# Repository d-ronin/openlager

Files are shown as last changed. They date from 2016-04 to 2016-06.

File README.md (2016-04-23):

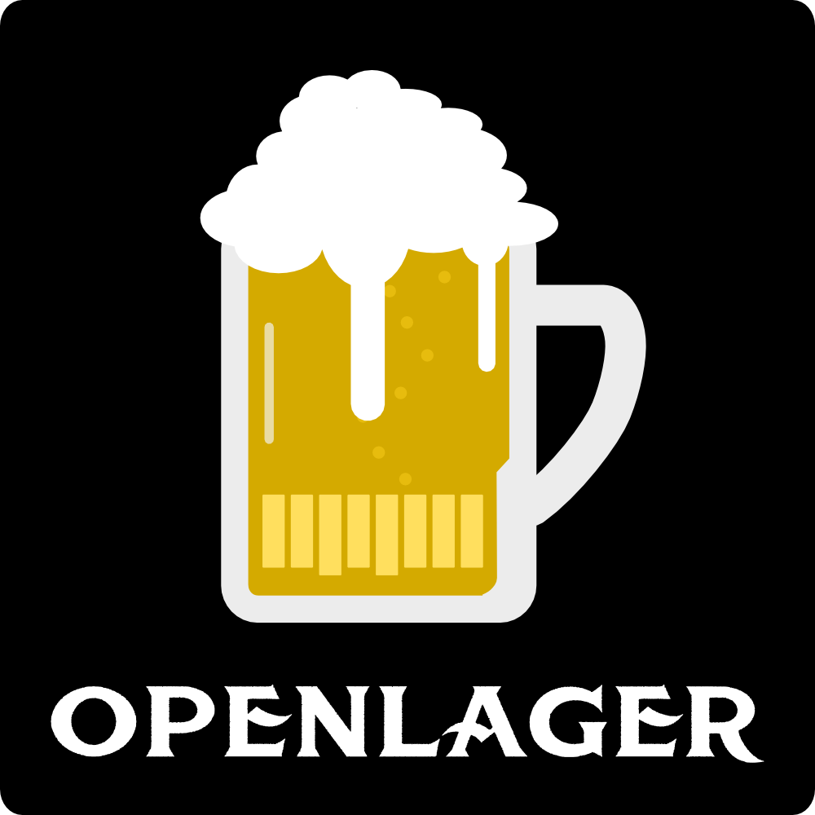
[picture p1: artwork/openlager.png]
openlager

STM32F4 based logging dongle for **HIGH RATE** logging

This project is inspired by [OpenLog](https://github.com/sparkfun/OpenLog).

*Why do something new?*  To attain higher rates!  The **openlager** hardware can accept data at high rates using slave SPI or fast async serial.  It uses a 4-wide SDIO interface to the card to support higher peak logging rates.  And the reasonable amount of memory buffer on the STM32F411 lets us ride out times when the SD card is busy erasing or doing other housekeeping without losing data.

The **openlager** hardware design and firmware are produced by the [dRonin](http://dronin.org) project, which produces high-quality flight controller software for drone racing and autonomous flight.  To log everything that's happening in a lossless fashion, high rate logs are required.  But we anticipate it being useful for a wide variety of applications.

# Licenses

The **openlager** hardware in `hardware/` is licensed under a Creative Commons Attribution 4.0 International License (CC BY 4.0), as contained in `hardware/LICENSE.txt`

The **openlager** firmware (and bootloader) in `src/`, `loader/`, and `shared/` is licensed under a simplified BSD license as found in `src/LICENSE.txt`

The openlager **logo** may only be used with permission from the dRonin project.

The **fatfs** library in `libs/fatfs` is licensed under the one-clause BSD license as found in the source files in that directory.

The **STM32F4xx_StdPeriph_Driver** library in `libs/STM32F4xx_StdPeriph_Driver` is largely licensed under a restrictive license that limits its usage to ST family processors.  To use this software on non-ST parts, the dependency on this library code must be removed.  Portions of this code (the `core_cm*` include headers) are licensed under a permissive 3 clause BSD license from ARM, as noted in the individual files.

The **mmcreg.h** file from FreeBSD in `libs/inc` is licensed under a simplified BSD license.

The **jsmn** library in `libs` is licensed under the MIT license.

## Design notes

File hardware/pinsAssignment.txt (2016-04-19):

Main interface:
	Pin 1 - SO
	Pin 2 - RX/CK
	Pin 3 - TX/CS
	Pin 4 - 5V
	Pin 5 - GND
	Pin 6 - SI
	Pin 7 - NRST

SD Card Interface:
	SDIO_CK  - PB15
	SDIO_CMD - PA6
	SDIO_D0  - PB7
	SDIO_D1  - PA8
	SDIO_D2  - PA9
	SDIO_D3  - PB5

FC Interface:
	UART1_TX/SPI1_NSS  - PA15
	UART1_RX/SPI1_SCK  - PA3
	SPI1_MISO          - PA4
	SPI1_MOSI          - PA7

Status LED:
	Active LOW - PB9

BOOT Interface:
	BOOT0 - 10k pull-down, pad for jumpering to +3V3
	BOOT1 - 10k pull-down

Bootloader Interface:
	RX_SCK - shared with SWDIO
	MOSI   - shared with SWCLK
	NRST

HW Rev ID:
	Rev A: PB12 PB13 PB14 - All LOW

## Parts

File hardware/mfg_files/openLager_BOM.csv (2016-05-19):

Reference | Quantity | Value | Footprint | Datasheet | Mfg Name | Mfg PN | Link
C1 C4 | 2 | 10uF | openLagerFootprints:C_0402 | http://datasheet.octopart.com/CL05A106MP5NUNC-Samsung-datasheet-34153002.pdf | Samsung | CL05A106MP5NUNC | https://octopart.com/cl05a106mp5nunc-samsung-22457395
C5 | 1 | 1uF | openLagerFootprints:C_0402 | http://datasheet.octopart.com/GRM-Series-Murata-datasheet-family-27.pdf | Murata | GRM155R70J105MA12D | https://octopart.com/grm155r70j105ma12d-murata-23261089
C6 | 1 | 4.7uF | openLagerFootprints:C_0402 | http://www.samsungsem.com/kr/support/product-search/mlcc/__icsFiles/afieldfile/2015/08/14/S_CL05A475MQ5NQNC.pdf | Samsung | CL05A475MQ5NQNC | https://octopart.com/cl05a475mq5nqnc-samsung-24957780
C3 C7 C8 | 3 | 0.1uF | openLagerFootprints:C_0402 | http://datasheet.octopart.com/GRM155R70J104KA01D-Murata-datasheet-14400549.pdf | Murata | GRM155R70J104KA01D | https://octopart.com/grm155r70j104ka01d-murata-17930200
D1 | 1 | LG L29K-F2J1-24 | openLagerFootprints:LED_0603 | http://datasheet.octopart.com/LG-L29K-F2J1-24-Osram-datasheet-41480516.pdf | Osram Opto | LG L29K-F2J1-24 | https://octopart.com/lg+l29k-f2j1-24-osram+opto-31119809
D2 | 1 | LS L29K-G1J2-1-Z | openLagerFootprints:LED_0603 | http://datasheet.octopart.com/Q65110A1757-Osram-Opto-datasheet-31819788.pdf | Osram Opto | LS L29K-G1J2-1-Z | https://octopart.com/ls+l29k-g1j2-1-z-osram+opto-31093939
J1 | 1 | CONN_01X06 | openLagerFootprints:Socket_Strip_Straight_1x06 | DNP | DNP | DNP | DNP
J2 | 1 | DM3CS-SF | openLagerFootprints:HRS_DM3CS-SF | http://datasheet.octopart.com/DM3CS-SF-Hirose-datasheet-62290579.pdf | Hirose | DM3CS-SF | https://octopart.com/dm3cs-sf-hirose-44525751
R1 R3 R4 | 3 | 10k | openLagerFootprints:R_0402 | http://datasheet.octopart.com/RC0402JR-0710KL-Yageo-datasheet-10408619.pdf | Yageo | RC0402JR-0710KL | https://octopart.com/rc0402jr-0710kl-yageo-55458470
R12 R13 | 2 | 330R | openLagerFootprints:R_0402 | http://datasheet.octopart.com/RC0402JR-07330RL-Yageo-datasheet-10408619.pdf | Yageo | RC0402JR-07330RL | https://octopart.com/rc0402jr-07330rl-yageo-40021082
R2 | 1 | DNP | openLagerFootprints:R_0402 | DNP | DNP | DNP | DNP
R5 R6 R7 R8 | 4 | 22R | openLagerFootprints:R_0402 | http://datasheet.octopart.com/RC0402JR-0722RL-Yageo-datasheet-10408619.pdf | Yageo | RC0402JR-0722RL | https://octopart.com/rc0402jr-0722rl-yageo-1173206
R10 R9 | 2 | 47k | openLagerFootprints:R_0402 | http://datasheet.octopart.com/RC0402JR-0747KL-Yageo-datasheet-10408619.pdf | Yageo | RC0402JR-0747KL | https://octopart.com/rc0402jr-0747kl-yageo-39834460
TP1 | 1 | TEST_1P | openLagerFootprints:Socket_Strip_Straight_1x01 | DNP | DNP | DNP | DNP
TP2 TP3 | 2 | TEST_1P | openLagerFootprints:TP | DNP | DNP | DNP | DNP
U1 | 1 | STM32F411CEUx | openLagerFootprints:QFN-48-1EP_7x7mm_Pitch0.5mm | http://datasheet.octopart.com/STM32F411CEU6-STMicroelectronics-datasheet-27102711.pdf | ST Microelectronics | STM32F411CEU6 | https://octopart.com/stm32f411ceu6-stmicroelectronics-47202664
U2 | 1 | SPX3819M5-L-3-3 | openLagerFootprints:SOT95P280X145-5N | http://datasheet.octopart.com/SPX3819M5-L-3-3-TR-Exar-datasheet-13046336.pdf | Exar | SPX3819M5-L-3-3/TR | https://octopart.com/spx3819m5-l-3-3%2Ftr-exar-9290124
Y1 | 1 | CSTCE8M00G15L99 | openLagerFootprints:X3-SMD-3.6X1.3X0.8MM | http://datasheet.octopart.com/CSTCE8M00G15L99-R0-Murata-datasheet-13544362.pdf | Murata | CSTCE8M00G15L99-R0 | https://octopart.com/cstce8m00g15l99-r0-murata-17751576

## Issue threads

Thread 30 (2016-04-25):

SDIO receive / transmit should use DMA

mlyle, 2016-04-25:
Along with trying to be aligned / zerocopy in all cases...

mlyle, 2016-04-25:
This is probably the limiting factor preventing higher USART rates right now.  Very very easy to underrun the FIFO.  (get 'WFLAG' morse after a few seconds sustained at 576000 bps)

mlyle, 2016-04-26:
Adding retries (#31) gets around the 'WFLAG' for now, but that's hardly good for performance...

mlyle, 2016-05-02:
1.5megabaud pegged loses nothing currently.  2megabaud pegged loses occasional bits when fully pegged-- e.g. first loss is 200 bytes 1331000-ish bytes into a session.

Gyros+accels+attitude+stabilizationdesired+actuatordesired uavtalk:
```
12+16+28+24+17=97
97 + 11*5=152
```
results in 152000 characters per second at 1000Hz, or precisely 76% utilization on a 2mbaud channel.  This should be absolutely no problem for loss with the current scenario.  And there's still multiblock writes and a few K of buffering available to make this work better.

Closed 2016-05-02.

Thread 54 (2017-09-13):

improvement - flush & new file

LubinKerhuel, 2017-09-13:
First, let's say this logger is great and support much higher logging rate than its openlog counterpart. I've been looking for it for a very long time. Radio link to log were so-so, and openlog was too slow.

There are few pin which seems not used when using the UART connexion ; Is there any possibility to use one pin to force flush of current log and stop log when toggled to 0, and start a new file when toggled back to 1 ?
Currently, I added one wire which is doing it in a tiny hole nearby TP2 (might be a reset pin?). But that is certainly not the best way to do even if it works.

Another side remark: green led is too bright compared to red one. Red led is the one which provide useful information in the field, but I can hardly see it.

mlyle, 2017-09-13:
Thanks for the feedback.  --- can look into the possibility of doing this.

Where'd you get yours?  Note that I made a small batch myself, but all current production is just from Airbot who downloaded the design files and chose their own components/LEDs etc to put on.

LubinKerhuel, 2017-09-15:
I found only 2 place to buy it. I pick it at Airbot because of its slightly lower shipping rate for my place as I remember (France). I would pick the other one next time if it is the "original" one (yours?).

On performance feedback: setting the baudrate at 2 470 000, using 45% of the bandwidth (10.9 kbyte/s) for 15 minutes ~ half an hour. I get 0% error with old SD Cards formatted with either fat16 or fat32. That's all ok. (data recorded from a dsPIC)

kaspergrubbe, 2019-05-14:
@mlyle Is the one from RDQ from you or from Airbot https://www.readytoflyquads.com/high-rate-f4-data-logger-openlager ?

I would like to buy one, but would prefer to buy from dRonin.

tracernz, 2019-05-16:
@kaspergrubbe Buy it from wherever you can get it. The idea of making the design fully open from the start was that as many manufacturers as possible would pick it up and make the board easily available for everyone.

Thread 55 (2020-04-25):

Help diagnosing if working?

dan-van, 2020-04-25:
Hi I've been trying to connect an OpenLager (purchased through Amazon.com) to a MATEKF405 running Betaflight 4.1.1.
No joy. I'm beginning to suspect maybe a problem with Betaflight, or my FC, but it would be nice to know OpenLager is working.
I bought a DigitalLogic analyser, but my FC doesn't seem to be trying to pull voltage low on the TX UARTS when they are set to Blackbox (ok, there is actually a single pulse on board startup, but nothing after that).
If I get a USB -> UART bridge, is it somehow possible to write data to the openlager unit from my laptop?

--- more detail on my betaflight setup ---
I get a zero-byte LOG000.TXT file each time I power up the flight controller.
I have betaflight set up to activate BB logging when armed.
Arming / disarming does not create a new file. Only powering the board creates a new file.
I've tried numerous different baud rates and 2 different TX pads on my FC (obviously updating the LAGER.CFG file).
Changing preallocGrow=true causes a 105mb log file to be written (assuming related to the preallocBytes : 104857600 setting). Obviously I can't parse this file.

Many thanks!

dan-van, 2020-04-27:
An update to this.
I got an FT232 and can send asci to the OpenLager.
The unit logs different length LOG000.TXT files depending on how many chars I type (using `screen /dev/...usbserial... <baud>`). The strange thing is that the file is just full of 0x00 values, no asci chars (I was expecting it to just capture the data on the TX line).
Maybe I've got some other config problems or somehow mismatched baud rates, but should I expect to type asci in a terminal and capture the same bytestream on the openlager?

tracernz, 2020-04-27:
> should I expect to type asci in a terminal and capture the same bytestream on the openlager?

Yes, that should be what happens. The most likely scenario is one or more of the parameters is mismatched (baud rate, parity, stop bits), most likely baud rate. The openlager defaults to 115200 baud, but can be overridden with the config file (lager.cfg on the SD card, which will be created from defaults if it doesn't exist). The other parameters cannot be changed on the openlager.

dan-van, 2020-04-27:
Many thanks, I'll use something more controllable than 'screen' for partiy bits etc.
Closing the question: Having an FT232RL seems like the best way to verify operation (I guess technically there could be a self-test mode that relies on TX and RX being bridged on the OpenLager, but seems like poor effort / reward at this stage).

In case it helps anyone else (some other things that had me puzzled for a while):
Betaflight (4.1.1) with `blackbox_mode=NORMAL` doesn't start emitting data until the quad is fully armed. i.e. just configuring Blackbox to start in line with your 'arm' switch from your transmitter is not sufficient. The board needs to pass all pre-arm checks (i.e. go to full 'props spinning', and not have USB attached!).

Setting blackbox_mode=ALWAYS does emit UART data from power-on (seen on logic probe), but it's not really designed to work (e.g. missing headers are probably expected) and at time of writing the OpenLager didn't actually flush any data. I've probably messed up baud rates. Once I've verified capturing accurate ascii data from my laptop I'll go back to that.

Many thanks for the project!

Closed 2020-04-27.

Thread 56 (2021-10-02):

Does 4 bit mode really work ?  It is turned off in openlager.c's sd_init() call

mirov, 2021-10-02:
I found that my openlager running an image built from this Github source has a "false" parameter to the sd_init() call in openlager.c, and that means "don't use fourbit mode".  Is it turned off for a reason ?  I flipped it to true and can log for a while, but then it hangs.  Is that because the HW reference design only has a 47K pullup on SDIO_D0 ?  The other pins seem to have the pullups in the STM32 GPIOs turned on, but perhaps they are too weak for 19.2MHz.

mlyle, 2021-10-02:
It's turned off because SD bandwidth was not limiting performance on any of the cards we used.  The limiting factor wasn't the bus interface but the amount of time the card spent busy after I/O requests.  Bigger buffers / STM32F412, allowing bigger I/O operations per flush, would make a bigger difference than bus speed.

Of course, there's been a couple of years in progress in cards, so maybe there's some cards that would benefit from 4X now.  It was never really tested.

Pullup on SD bus lines are required during initialization but are not used during signalling-- the card enters a push-pull state.  A 47k pullup would not be fast enough for open collector at 1MHz, let alone 19.2MHz.  So that is not likely to be your issue.

mirov, 2021-10-02:
Hi Michael, I'll bet you were surprised to see activity on this after a few
years of quiet.  Hmmm, I wasn't sure if the 47K was simply there to hold
the high state.

I've got the Lager in a power sensitive design and am trying to find knobs
to drop consumption.  I'm sending data in bursts at 1Mbps, but at an
average of about 64KB/sec.  I found that things seem to be stable with the
core clock rate dropped down to 48MHz, and the SD clock down to 9.6 (that
saves around 10mA).  I'm looking at dropping my supply rail down to 2.7V,
which I believe will be OK with the newer 32GB cards I'm using - and that
will drop my upstream battery current by about 10% more.  I found that
preallocating a large enough block drops the power as well.

The once seemingly huge 128KB buffer of the 'F11 only gives me a few
seconds of buffer, but if it isn't keeping up my application runs so long
that a bigger buffer isn't going to help.

Oddly, every now and then I can get the device to log at a really low (like
half) power consumption.  Are there any magic block sizes/timing
preferences that I can exploit to keep it in a more efficient mode ?  I can
with some effort change the size of my serial data blocks, batch them up,
etc.  At the moment I'm logging in ASCII 'cause it is so easy to debug and
parse.  I can cut my byte count down by 2-3x if I switch to binary, but it
isn't clear if that will help the STM/uSD save power (busywaits instead of
sleeps for example).

-Russ

On Sat, Oct 2, 2021 at 3:09 PM Michael Lyle ***@***.***>
wrote:

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

mlyle, 2021-10-03:
Interesting.   Downclocking wouldn't be the first thing I'd do-- I'd try to race-to-sleep instead.

Looks like right now usart_receive_chunk busywaits, so getting a wait-for-interrupt in there would likely be helpful.

Currently a bunch of peripheral clocks are on that aren't needed.  But then a lot of them can be disabled-- e.g. when SD is not doing a transaction, the peripheral can be paused.  It would be better to keep the clock rate high and then disable the clock as quickly as possible after a transaction finishes.

mirov, 2021-10-03:
Oh, I'd also much prefer full speed clocks (at least those that I need) and
sleeping the CPU until something wakes it up.  Add in some DMA to keep it
sleeping until things are really done and the power should be pretty low.
Alas, I have never worked with the STM series (I'm mostly a nRF52 guy).

With the core clock slowed down I get lower power, but the tradeoff is that
I also get periodic hangs with the LED stuck on.

-Russ

On Sat, Oct 2, 2021 at 6:49 PM Michael Lyle ***@***.***>
wrote:

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

mlyle, 2021-10-03:
Try calling __WFI in the loop in usart_receive_chunk.

mlyle, 2021-10-03:
(note SD uses DMA; though we don't sleep during SD transactions either.  But making USART use DMA is much harder, because we're trying to adaptively adjust our flush behavior based on both what the card is doing and the arrival rate of information).

mirov, 2021-10-03:
That saved about 30% of what it was consuming, that was a nice suggestion
(and I would bet that it doesn't introduce any odd instabilities).   I
assume we're waking up for any INT.  Are there reliable sources always
running to be sure we don't snooze forever in that loop ?  I don't know if
for example there's a timer running that periodically pops and will always
nudge us to check the loop termination condition.  If so, then are there
other spots we're spinning for significant amounts of time that we could
play the same trick ?  For example in shared/sdio.c there's a loop waiting
for SDIO_STA_DATAEND that from your earlier comments sounds like we spend
some time in.  I dropped a WFI in there and it seems like it save perhaps
1/2 mA (which I'll take, thank you).   But again, I don't know if that
introduces a possible deadlock...

I really appreciate the help !

-Russ

On Sat, Oct 2, 2021 at 9:35 PM Michael Lyle ***@***.***>
wrote:

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

mlyle, 2021-10-03:
The two things that allow leaving the USART loop are either a UART interrupt or a timeout expiring (and the time is updated by the systick "interrupt").  So there's no cost to performance there.

The same isn't quite true of the SDIO stuff, which isn't interrupt driven presently.  Systick will still show up and knock you out of that eventually, but there may be times that the sd bus is left unnecessarily idle.

The next thing I'd try to reduce consumption is to turn off the SD peripheral's clock at the end of sd_write/sd_read, and to turn it back on at the beginning of sd_write/sd_read.

    RCC_APB2PeriphClockCmd(RCC_APB2Periph_SDIO, ENABLE (or DISABLE);

main() turns on a bunch of peripheral clocks, and I think a lot of them are unused.  TIM1/TIM2/TIM3/TIM4/TIM5, and maybe SPI1.  OpenLager was mostly used on drones consuming hundreds of amperes, so there was absolutely no pressure to save a few milliamperes (and turning on all the clocks you *might* need saves a lot of confusion later).

P.S. --- I think you may have worked with my oldest brother Jim at Berkeley, Tandem, or Sun?  Looks like we're connected on LinkedIn.

mirov, 2021-10-03:
Jim Lyle?  Yeah that was only 30-40 years ago though!   I didn't realize
that the internet was this small...   I'm still an active HW guy, is he ?
Are you in the Bay Area also ?  We seem to be in the same time zone (Los
Altos for me).

I found OpenLager through my drone interests (actually fixed wing mostly)
and was looking for something that had better buffering than OpenLog.  My
application doesn't need raw performance, but I really don't want to drop
any samples.  It does however care a lot about power consumption.

Ouch!  Toggling the SDIO clock on/off actually increased the power by 10mA
.  Does that ClkCmd have a long settling time built in for a PLL to lock ?

-Russ

On Sun, Oct 3, 2021 at 10:14 AM Michael Lyle ***@***.***>
wrote:

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

mlyle, 2021-10-03:
Re: PLL-- that's a good question.  No-- the "48MHz" SDIO clock is derived from the main PLL which needs to be locked to clock the main processor.  It should just be gating that on and off-- there should be no reason for power consumption to go up.  Quite odd.  Maybe it checks in with the card when we re-enable its clock and we have to wait for that.

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

It's not trivial to sleep while SD does operations in a correct way-- but it sounds like the benefit from that is small.
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
mirov, 2021-10-03:
I used to fly an Electra in the empty field across the street from Tandem
during lunch.  And at about that time I designed a UHF video transmitter to
hook a vidicon-based B/W Sony camera to it so I could do FPV back in the
late 80's or early 90's.  It worked, but I had to use a portable TV and a
hood to see things.  I still have the Electra, and was looking at it over
the Summer realizing that it can carry a *lot* of 18650 cells...

Bumping that timeout up by a lot (from 50 to 200) doesn't seem to do
anything.  I think that kicks in only really as an exception ?  I'm logging
data in a system that spits out a ~128 character line every 2mSec (though
normally fewer than 128).      I could pad it out so that it was always an
even 128 bytes if that would help keep things aligned.

I have now and then seen the current spike up ~30mA for a second or two,
I've assumed that the card is doing something internally.    Do the new
really fast cards (like 100+MB/s) just have a bunch of RAM inside to buffer
through that sort of thing ?  I've ordered a few types to try out...

-Russ

On Sun, Oct 3, 2021 at 12:39 PM Michael Lyle ***@***.***>
wrote:

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

mlyle, 2021-10-03:
>Bumping that timeout up by a lot (from 50 to 200) doesn't seem to do
anything.  I think that kicks in only really as an exception ?  I'm logging
data in a system that spits out a ~128 character line every 2mSec (though
normally fewer than 128).      I could pad it out so that it was always an
even 128 bytes if that would help keep things aligned.

Here is the logic:

Wait until:

* At least 2560 bytes have arrived (a minimum reasonable chunk to write), or
* at least 200ms (50 ticks) have passed.

And then write:

* 40k, if we have more than that to write (idea is to complete the write transaction and free up buffer ASAP, so this is a compromise between "finish fast before buffer fills" and throughput, else
* The maximum amount we can finish at 512 byte alignment with, if we have more than 512 to write, else
* Just whatever we have, otherwise.

So, it's a bit of a screwy heuristic that trades off throughput, SD card alignment, buffer management, and flush protection against losing data at power loss.

At (128/.002) =~ 64kbytes/sec, you'll be doing 2560 byte aligned increments, except when the SD card falls behind and you do larger writes.  Yes, changing the ticks won't change anything; increasing 2560 to 4096-10240 might.

mirov, 2021-10-03:
BTW, I'll bet your sensitivity to data loss and flushing buffers probably
comes from ejecting battery packs on impact...  I don't have that sort of
issue, I just don't want to drop samples because something got busy.

I tried 4096 and 10240 didn't cause the nominal power to budge I'm afraid.

Perhaps we've turned all the "good" knobs already, I think the Lager
portion of my system is really only using about 9mA at the moment, which
isn't too bad.  The total device draw is about 24mA though, so every mA is
a big deal (about 1.5 hours of run time).

I'm going to let things settle for a while and see if anything has broken.
The next change I make btw will likely be the utilization of the Lager
USART TX path to send state/status info to the upstream processor that is
at the moment open loop.  I think a single encoded byte now and then will
make little mysteries like a full card, write error, not finished booting
yet, etc easier to debug.

Again, thank you so much for your assistance over the last few days.  Say
high to Jim and let's hook up on LinkedIn.

-Russ

On Sun, Oct 3, 2021 at 1:08 PM Michael Lyle ***@***.***>
wrote:

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

mlyle, 2021-10-03:
9mA doesn't sound bad at all!  Yah, further gains are probably hard to find: this wasn't made to be power efficient at all-- but instead just to be reliable to get logs to storage no matter what.   Nice to "meet" you and best of luck with the system you're building.

Closed 2021-10-03.

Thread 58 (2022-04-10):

Problem with Openlager

rs3hc, 2022-04-10:
Sorry for posting it as a issue here but i cant find any detailed informations on the web.

i got a openlager from a buddy for logging a Betafpv Toothpick F722 2-6S AIO Brushless Flight Controller 35A(BLHeli_S) which dont offer storage...

I soldered 5V, GND and TX6 from FC to RX on openlager.
In Betafligth i configured UART6 as Blackbox logger ans 2000000 baud, ans Serials Logger, 2khz and Gyro_Scaled in the Blackbox section.
Should be ok...

I tried multipe SD Cards from Class4 over U1 32GB to U3 64GB A2 V30.... also tried all formats FAT/FAT32
Nothing works...

If i Power the FC the green LED on Openlager lit up correctly but the red LED (should be for write process?) never lit up.

Can anybody discripe how it should look like if it will work?

maciejlagowski, 2022-04-10:
same issue here, tried different SD cards, different file formats etc..

Zuldan, 2022-04-11:
I don’t know the answer to your issues but if you guys also mention which Openlager chip you are using it may help in the diagnosis. As far as I know there is an Airbot and JHEMCU version, possibly others exist…

maciejlagowski, 2022-04-11:
Mine is Airbot Openlager

rs3hc, 2022-04-11:
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

maciejlagowski, 2022-04-14:
My problem was solved by inserting a card with the lager.bin file to flash. Surprisingly now the device works :)

rs3hc, 2022-04-15:
> My problem was solved by inserting a card with the lager.bin file to flash. Surprisingly now the device works :)

Only "lager.bin"?
How long did it take?
What did the red LED while updating?

For what do we need these two other files? (bootlager.bin, ef_lager.bin)

maciejlagowski, 2022-04-15:
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

I put only lager.bin file on the SD, red LED was flashing for about 20 seconds maybe, then I powered it off and checked the SD card - there was config and log file.

rs3hc, 2022-04-15:
Oh OK..

I tried 3 sd cards with lager.bin and nothing happened. Only green Led was on

rs3hc, 2022-05-02:
Any one can help??

Closed 2023-07-12.

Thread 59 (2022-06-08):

Flashing Openlager via FTDI ?

rs3hc, 2022-06-08:
@mlyle or @droidicus

I have here an Openlager that did not work properly for me since the beginning.
It did put the lager.cfg on the card ... but only created empty log files.

So I copied the Lager.bin from "openlager_firmware_20160629" to the card, and tried to flash it with that.
(...a few more words about the "update process" would have been nice...).

I supplied it with 5V, the green LED was on all the time and the red one blinked a few times. I waited for 2 minutes.

But now it does not react at all. Only the green LED is on but the red one stays off and nothing is written to the card.

The same card works fine with another Openlager, which is why I exclude it as a source of error.

Is there a possibility to flash the µC via FTDI?

kind regards
Robert

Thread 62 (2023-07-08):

Openlager blinking RED LED and no files

rogerfpv1989, 2023-07-08:
Hi,
I just bought and connected an Openlager to my FETTEC G4-N FC. Upon applying power, grenn LED goes ON and RED LED goes on, blinking with a certain pattern. However no files are created on SD Card.
The RED LED blinking pattern stays ON forever (until power removal that is); it is present whether there is an SD Card installed or not; I've tried the recommended SD Card, and other SD cards (to up to 64GB) but nothing works. I've tried putting the lager.bin file on the SD cards, but nothing changes, same behaviour. It's like the Openlager is not reading the SD cards...any ideas? Need help!
Thaks in advance

mlyle, 2023-07-08:
Sounds like you probably have a defective board.  Talk to your vendor: we don't provide support.

The blinking pattern is morse code that will tell you the error, if that helps.

rogerfpv1989, 2023-07-12:
Thanks for the help.
So I am no morse expert, but with my phone camera (red LED is not easy to see right next to the very bright green LED) and a morse code translator, here's what I managed to decypher: DCARD+NC+DCARD+NC+ etc
What is this supposed to mean?

mlyle, 2023-07-12:
'CARD' indicates that it never received a reply from the SD card.  https://github.com/d-ronin/openlager/blob/master/src/openlager.c#L594C1-L597C10

rogerfpv89, 2023-07-12:
Alright, thanks. Can you tell me if there is a maximum size of Sd caed rho Openlager is able to handle? 16GB? 32GB? 64GB?

mlyle, 2023-07-12:
Oh, that's a good question.  It looks like we only have code to support SDHC, so that would be 32GB.

I don't believe it would fail with a 'CARD' error on larger cards, though.

mlyle, 2023-07-12:
Nevermind: SDHC and SDXC protocol are identical from our point of view; I'd expect larger cards to work (as long as they have a FAT32 filesystem and not exFAT).

I will try to try some large cards soon.  I'm not sure I ever used over 16GB.  In any case, this wouldn't explain your problem.

Closed 2023-07-08.

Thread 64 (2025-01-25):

Files are loading into BB but no data

jimmy6616, 2025-01-25:
Tried Openlager on a Rotorflight heli, tried #2 different helis and getting the attached. This shows the headers fine in Blackbox but no actual data. Can you advise please

[LOG000.TXT](https://github.com/user-attachments/files/18547630/LOG000.TXT)

mlyle, 2025-01-26:
I don't know much about current blackbox tooling as I use openlager for different things.

But I opened your file on blackbox.betaflight.com and all the data seems fine.

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

Closed 2025-01-26.

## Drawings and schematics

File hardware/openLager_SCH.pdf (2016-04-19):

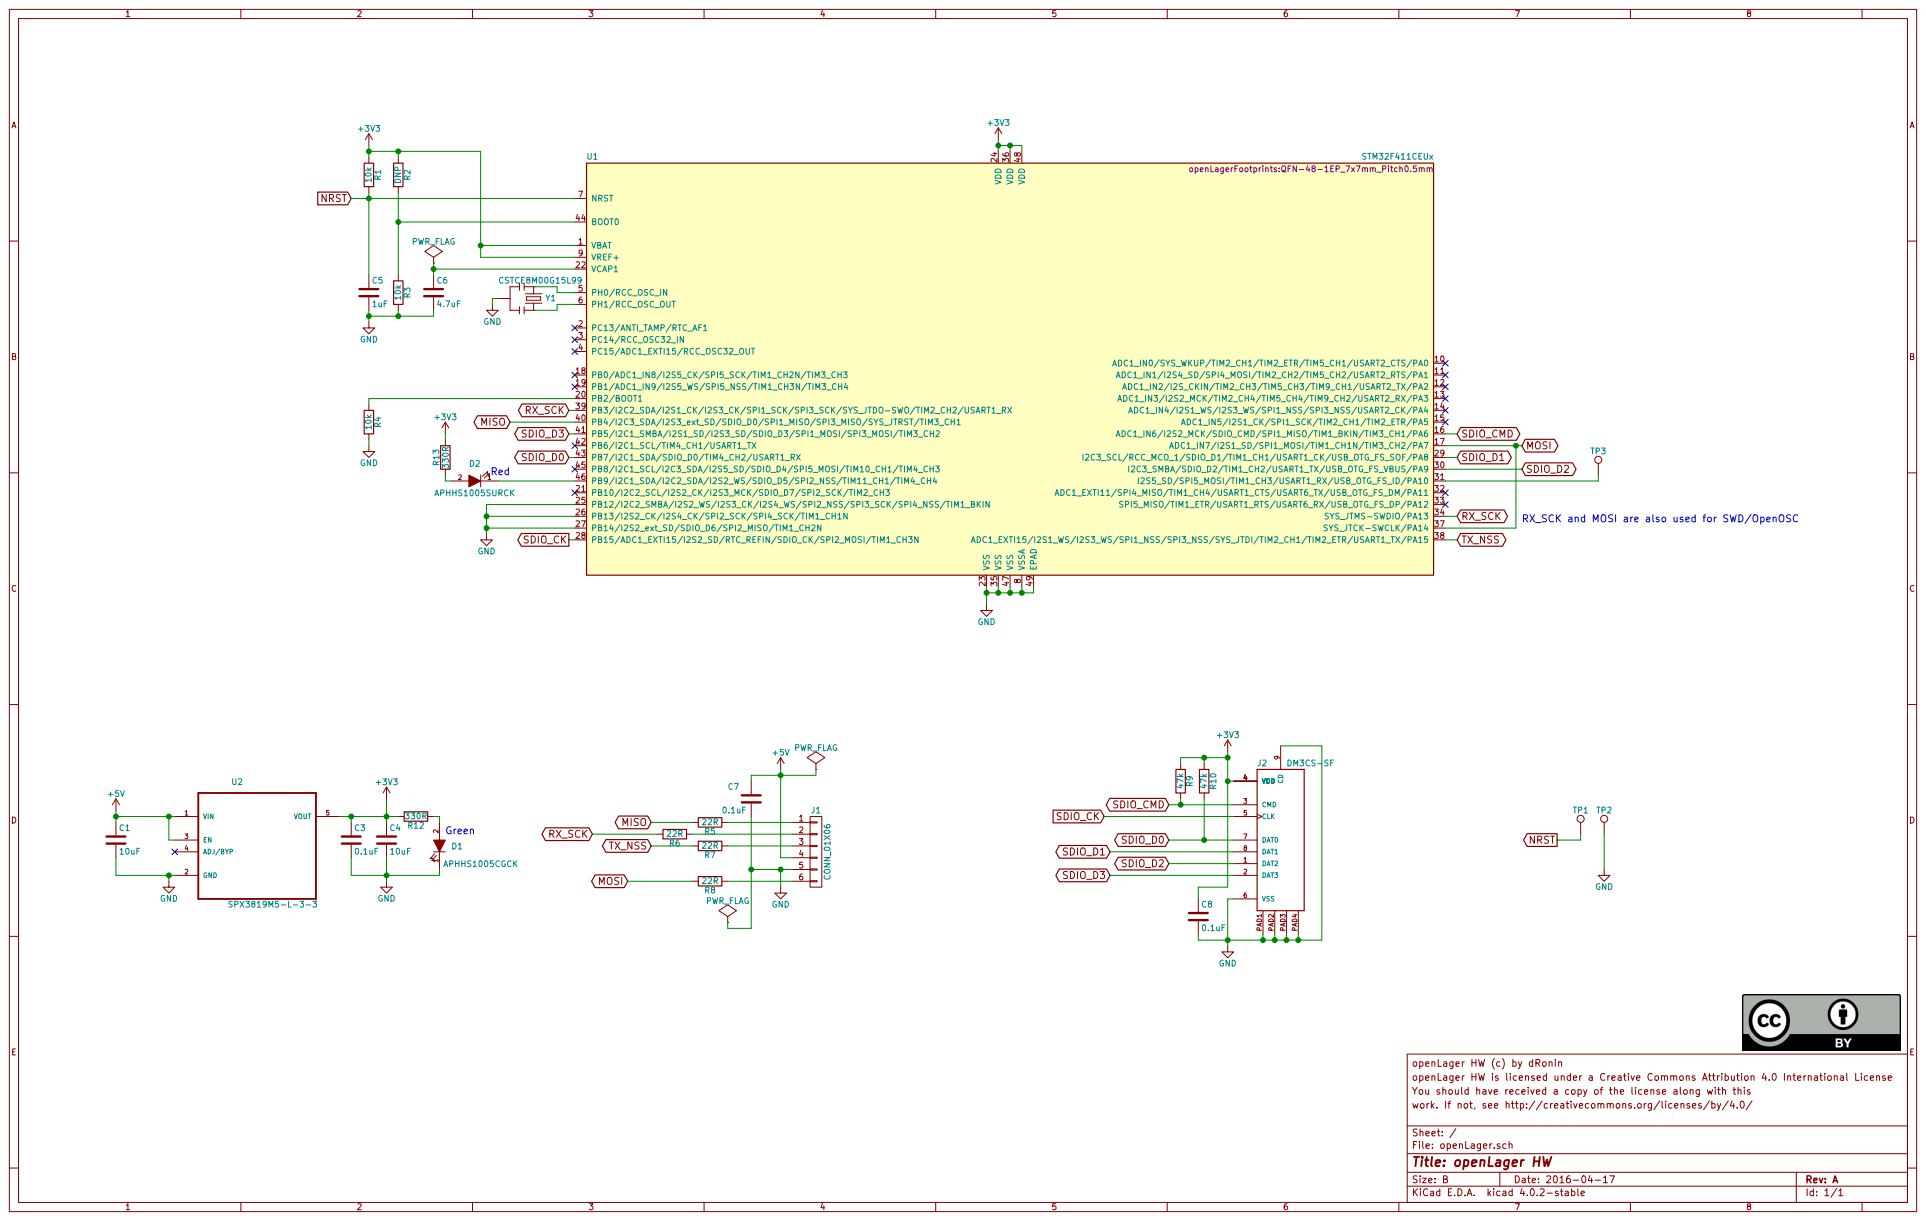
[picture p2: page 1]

openLager HW (c) by dRonin
openLager HW is licensed under a Creative Commons Attribution 4.0 International License
You should have received a copy of the license along with this
File: openLager.sch Sheet: / work. If not, see http://creativecommons.org/licenses/by/4.0/

Id: 1/1 Title: openLager HW

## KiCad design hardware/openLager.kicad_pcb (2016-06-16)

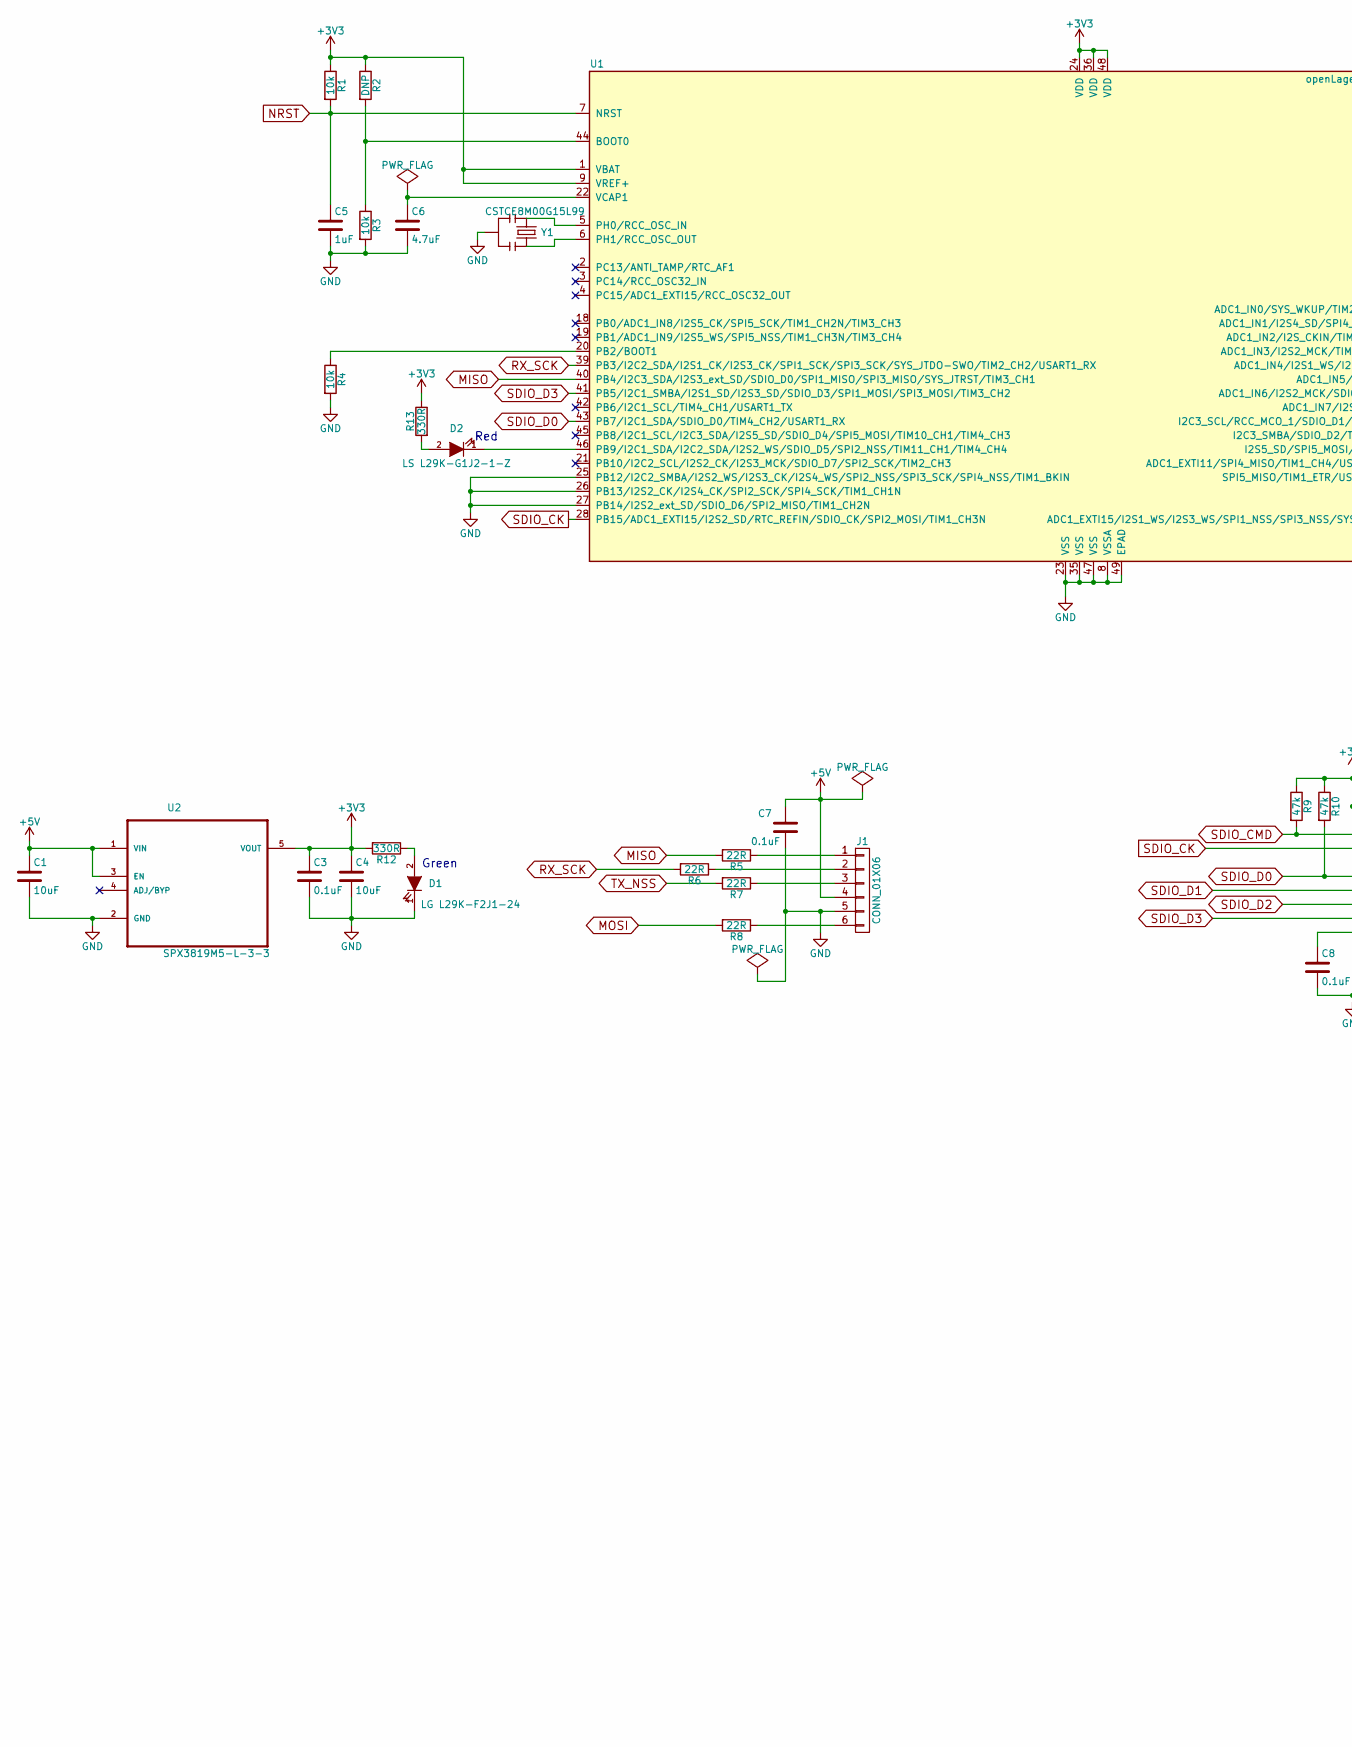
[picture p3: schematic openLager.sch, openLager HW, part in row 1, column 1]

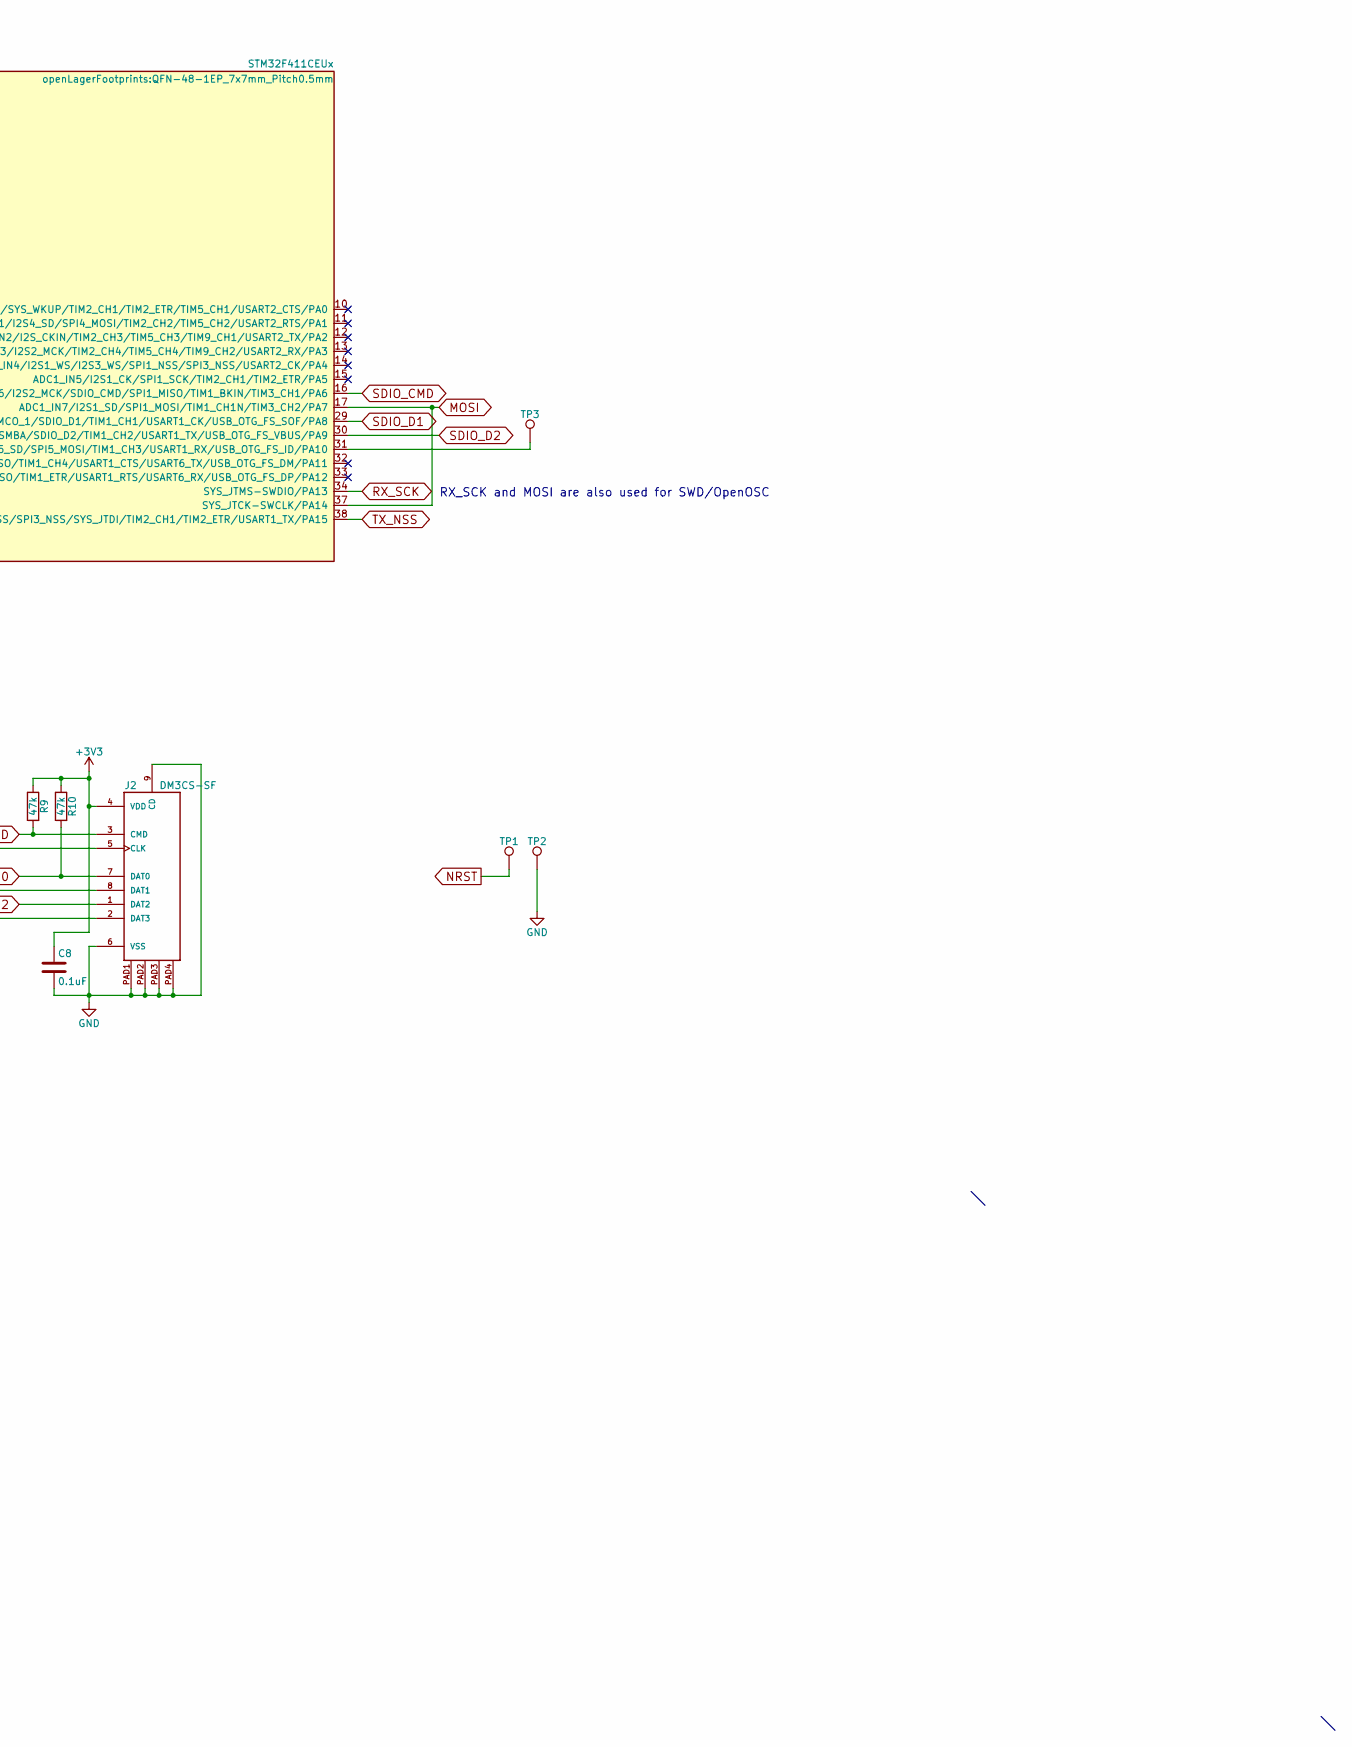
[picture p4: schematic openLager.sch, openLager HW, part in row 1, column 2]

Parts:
C1, C4: 10uF; C_0402; Mfg PN CL05A106MP5NUNC
C3, C7, C8: 0.1uF; C_0402; Mfg PN GRM155R70J104KA01D
C5: 1uF; C_0402; Mfg PN GRM155R70J105MA12D
C6: 4.7uF; C_0402; Mfg PN CL05A475MQ5NQNC
D1: LG L29K-F2J1-24; LED_0603; Mfg PN LG L29K-F2J1-24
D2: LS L29K-G1J2-1-Z; LED_0603; Mfg PN LS L29K-G1J2-1-Z
J1: CONN_01X06; Socket_Strip_Straight_1x06; Mfg PN DNP
J2: DM3CS-SF; HRS_DM3CS-SF; Mfg PN DM3CS-SF
R1, R3, R4: 10k; R_0402; Mfg PN RC0402JR-0710KL
R2: DNP; R_0402; Mfg PN DNP
R5, R6, R7, R8: 22R; R_0402; Mfg PN RC0402JR-0722RL
R9, R10: 47k; R_0402; Mfg PN RC0402JR-0747KL
R12, R13: 330R; R_0402; Mfg PN RC0402JR-07330RL
TP1, TP2, TP3: TEST_1P; TP; Mfg PN DNP
U1: STM32F411CEUx; QFN-48-1EP_7x7mm_Pitch0.5mm; Mfg PN STM32F411CEU6
U2: SPX3819M5-L-3-3; SOT95P280X145-5N; Mfg PN SPX3819M5-L-3-3/TR
Y1: CSTCE8M00G15L99; X3-SMD-3.6X1.3X0.8MM; Mfg PN CSTCE8M00G15L99-R0

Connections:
+3V3: C3.1, C4.1, C8.1, J2.4 (VDD), R1.1, R2.1, R9.1, R10.1, R12.2, R13.1, U1.1 (VBAT), U1.9 (VREF+), U1.24 (VDD), U1.36 (VDD), U1.48 (VDD), U2.5 (VOUT)
+5V: C1.1, C7.1, J1.4, U2.1 (VIN), U2.3 (EN)
GND: C1.2, C3.2, C4.2, C5.2, C6.2, C7.2, C8.2, D1.1 (K), J1.5, J2.6 (VSS), J2.9 (CD), J2.PAD1, J2.PAD2, J2.PAD3, J2.PAD4, R3.2, R4.2, TP2.1, U1.8 (VSSA), U1.23 (VSS), U1.25 (PB12/I2C2_SMBA/I2S2_WS/I2S3_CK/I2S4_WS/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), U1.26 (PB13/I2S2_CK/I2S4_CK/SPI2_SCK/SPI4_SCK/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), U1.27 (PB14/I2S2_ext_SD/SDIO_D6/SPI2_MISO/TIM1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), U1.35 (VSS), U1.47 (VSS), U1.49 (EPAD), U2.2 (GND), Y1.2
MISO: R5.2, U1.40 (PB4/I2C3_SDA/I2S3_ext_SD/SDIO_D0/SPI1_M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)
MOSI: R8.2, U1.17 (ADC1_IN7/I2S1_SD/SPI1_MOSI/TIM1_CH1N/TI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), U1.37 (SYS_JTCK-SWCLK/PA14)
NRST: C5.1, R1.2, TP1.1, U1.7 (NRST)
unnamed: C6.1, U1.22 (VCAP1)
unnamed: D1.2 (A), R12.1
unnamed: D2.1 (K), U1.46 (PB9/I2C1_SDA/I2C2_SDA/I2S2_WS/SDIO_D5/S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)
unnamed: D2.2 (A), R13.2
unnamed: J1.1, R5.1
unnamed: J1.2, R6.1
unnamed: J1.3, R7.1
unnamed: J1.6, R8.1
unnamed: R2.2, R3.1, U1.44 (BOOT0)
unnamed: R4.1, U1.20 (PB2/BOOT1)
unnamed: TP3.1, U1.31 (I2S5_SD/SPI5_MOSI/TIM1_CH3/USART1_RX/US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)
unnamed: U1.5 (PH0/RCC_OSC_IN), Y1.1
unnamed: U1.6 (PH1/RCC_OSC_OUT), Y1.3
RX_SCK: R6.2, U1.34 (SYS_JTMS-SWDIO/PA13), U1.39 (PB3/I2C2_SDA/I2S1_CK/I2S3_CK/SPI1_SCK/S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)
SDIO_CK: J2.5 (CLK), U1.28 (PB15/ADC1_EXTI15/I2S2_SD/RTC_REFIN/SDIO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)
SDIO_CMD: J2.3 (CMD), R9.2, U1.16 (ADC1_IN6/I2S2_MCK/SDIO_CMD/SPI1_MISO/TI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)
SDIO_D0: J2.7 (DAT0), R10.2, U1.43 (PB7/I2C1_SDA/SDIO_D0/TIM4_CH2/USART1_RX)
SDIO_D1: J2.8 (DAT1), U1.29 (I2C3_SCL/RCC_MCO_1/SDIO_D1/TIM1_CH1/USA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)
SDIO_D2: J2.1 (DAT2), U1.30 (I2C3_SMBA/SDIO_D2/TIM1_CH2/USART1_TX/US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)
SDIO_D3: J2.2 (DAT3), U1.41 (PB5/I2C1_SMBA/I2S1_SD/I2S3_SD/SDIO_D3/S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)
TX_NSS: R7.2, U1.38 (ADC1_EXTI15/I2S1_WS/I2S3_WS/SPI1_NSS/SP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)

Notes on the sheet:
Green
Red
RX_SCK and MOSI are also used for SWD/OpenOSC

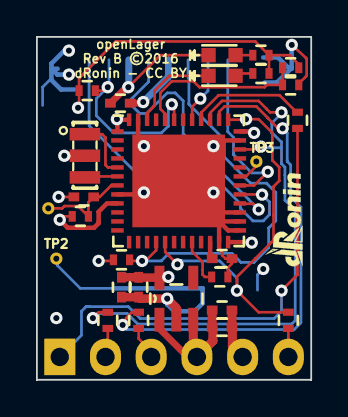
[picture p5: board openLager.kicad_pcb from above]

Board: 4 copper layers, 15.2 x 19.0 mm, 29 parts (1 on the bottom side), 27 nets.

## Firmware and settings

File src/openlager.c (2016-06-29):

// OpenLager main
//
// Copyright (c) 2016, dRonin
// All rights reserved.
// 
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
// THIS SOFTWARE IS PROVIDED BY THE COPYRIGHT HOLDERS AND CONTRIBUTORS "AS IS" AND
// ANY EXPRESS OR IMPLIED WARRANTIES, INCLUDING, BUT NOT LIMITED TO, THE IMPLIED
// WARRANTIES OF MERCHANTABILITY AND FITNESS FOR A PARTICULAR PURPOSE ARE
// DISCLAIMED. IN NO EVENT SHALL THE COPYRIGHT OWNER OR CONTRIBUTORS BE LIABLE FOR
// ANY DIRECT, INDIRECT, INCIDENTAL, SPECIAL, EXEMPLARY, OR CONSEQUENTIAL DAMAGES
// (INCLUDING, BUT NOT LIMITED TO, PROCUREMENT OF SUBSTITUTE GOODS OR SERVICES;
// LOSS OF USE, DATA, OR PROFITS; OR BUSINESS INTERRUPTION) HOWEVER CAUSED AND
// ON ANY THEORY OF LIABILITY, WHETHER IN CONTRACT, STRICT LIABILITY, OR TORT
// (INCLUDING NEGLIGENCE OR OTHERWISE) ARISING IN ANY WAY OUT OF THE USE OF THIS
// SOFTWARE, EVEN IF ADVISED OF THE POSSIBILITY OF SUCH DAMAGE.
//

#include <stdbool.h>
#include <string.h>
#include <unistd.h>

#include <ff.h>
#include <led.h>
#include <sdio.h>
#include <usart.h>

#include <stm32f4xx_rcc.h>
#include <systick_handler.h>

#include <jsmn.h>

#include <lagercfg.h>

#ifndef MIN
#define MIN(a,b) \
	({ __typeof__ (a) _a = (a); \
	 __typeof__ (b) _b = (b); \
	 _a < _b ? _a : _b; })
#endif

const void *_interrupt_vectors[FPU_IRQn] __attribute((section(".interrupt_vectors"))) = {
	[USART1_IRQn] = usart_int_handler
};

static FATFS fatfs;

static uint32_t cfg_baudrate = 115200;
static uint32_t cfg_prealloc = 0;
static bool cfg_prealloc_grow = false;
static bool cfg_bist = false;
static bool osc_err = false;


#define CFGFILE_NAME "lager.cfg"

// Must have non-digit characters before the digit characters.
#define LOGNAME_FMT "log000.txt"

#define NELEMENTS(x) (sizeof(x) / sizeof(*(x)))

/* Configuration functions */
static int parse_num(const char *cfg_buf, jsmntok_t *t) {
	int value = 0;
	bool neg = false;

	for (int pos = t->start; pos < t->end; pos++) {
		char c = cfg_buf[pos];

		if ((c == '-') && (pos == t->start)) {
			neg = true;
			continue;
		}

		if ((c < '0') || (c > '9')) {
			led_panic("?");
		}

		value *= 10;

		value += c - '0';
	}

	if (neg) {
		return -value;
	}

	return value;
}

static bool parse_bool(const char *cfg_buf, jsmntok_t *t) {
	switch (cfg_buf[t->start]) {
		case 't':
		case 'T':
			return true;
		case 'f':
		case 'F':
			return false;
		default:
			led_panic("?");
	}

	return false;	// Unreachable
}

static inline bool compare_key(const char *cfg_buf, jsmntok_t *t,
		const char *value, jsmntype_t typ) {
	if ((t->end - t->start) != strlen(value)) {
		return false;
	}

	// Technically we should be case sensitive, but.. Meh!
	if (strncasecmp(value, cfg_buf + t->start,
				t->end - t->start)) {
		return false;
	}

	// OK, the key matches.  Is the value of the expected type? 
	// if not, panic (invalid config)
	if (typ != t[1].type) {
		led_panic("?");
	}

	return true;
}

// Try to load a config file.  If it doesn't exist, create it.
// If we can't load after that, PANNNNIC.
void process_config() {
	FIL cfg_file;

	FRESULT res = f_open(&cfg_file, CFGFILE_NAME, FA_WRITE | FA_CREATE_NEW);

	if (res == FR_OK) {
		UINT wr_len = sizeof(lager_cfg);
		UINT written;
		res = f_write(&cfg_file, lager_cfg, wr_len, &written);

		if (res != FR_OK) {
			led_panic("WCFG");
		}

		if (written != wr_len) {
			led_panic("FULL");
		}

		f_close(&cfg_file);
	} else if (res != FR_EXIST) {
		led_panic("WCFG2");
	}

	res = f_open(&cfg_file, CFGFILE_NAME, FA_READ | FA_OPEN_EXISTING);

	if (res != FR_OK) {
		led_panic("RCFG");
	}

	char cfg_buf[4096];

	char cfg_morse[128];
	cfg_morse[0] = 0;

	UINT amount;

        if (FR_OK != f_read(&cfg_file, cfg_buf, sizeof(cfg_buf), &amount)) {
		led_panic("RCFG");
	}

	if (amount == 0 || amount >= sizeof(cfg_buf)) {
		led_panic("RCFG");
	}

	jsmntok_t tokens[100];
	jsmn_parser parser;

	jsmn_init(&parser);

	/* parse config */
	int num_tokens = jsmn_parse(&parser, cfg_buf, amount, tokens, 100);

	// Minimal should be JSMN_OBJECT 
	if (num_tokens < 1) {
		// ..--..
		led_panic("?");
	}

	int skip_count = 0;

	if (tokens[0].type != JSMN_OBJECT) {
		// ..--..
		led_panic("?");
	}

	// tokens-1 to guarantee that there's always room for a value after
	// our string key..
	for (int i=1; i<(num_tokens-1); i++) {
		jsmntok_t *t = tokens + i;
		jsmntok_t *next = t + 1;

		if (skip_count) {
			skip_count--;

			if ((t->type == JSMN_ARRAY) ||
					(t->type == JSMN_OBJECT)) {
				skip_count += t->size;
			}

			continue;
		}

		if (t->type != JSMN_STRING) {
			led_panic("?");
		}

		/* OK, it's a string. */

		if (compare_key(cfg_buf, t, "startupMorse", JSMN_STRING)) {
			int len = MIN(next->end - next->start, sizeof(cfg_morse)-1);

			memcpy(cfg_morse, cfg_buf + next->start, len);
			cfg_morse[len] = 0;
		} else if (compare_key(cfg_buf, t, "useSPI", JSMN_PRIMITIVE)) {
			if (parse_bool(cfg_buf, next)) {
				// XXX SPI not supported yet
				led_panic("?SPI?");
			}
		} else if (compare_key(cfg_buf, t, "baudRate", JSMN_PRIMITIVE)) {
			cfg_baudrate = parse_num(cfg_buf, next);
		} else if (compare_key(cfg_buf, t, "preallocBytes", JSMN_PRIMITIVE)) {
			cfg_prealloc = parse_num(cfg_buf, next);
		} else if (compare_key(cfg_buf, t, "preallocGrow", JSMN_PRIMITIVE)) {
			cfg_prealloc_grow = parse_bool(cfg_buf, next);
		} else if (compare_key(cfg_buf, t, "builtInSelfTest", JSMN_PRIMITIVE)) {
			cfg_bist = parse_bool(cfg_buf, next);
		}

		i++;	// Skip the value too on next iter.
	}

	f_close(&cfg_file);

	if (cfg_morse[0]) {
		led_send_morse(cfg_morse);
	}
}

static bool is_digit(char c) {
	if (c < '0') return false;
	if (c > '9') return false;

	return true;
}

static int advance_filename(char *f) {
	while (*f && (!is_digit(*f))) {
		f++;
	}

	if (!*f) return -1;	// No digits in string

	while (is_digit(*f)) {
		f++;
	}

	f--;			// Scan backwards

	// Now we're at the last digit.  Increment the number, with ripple
	// carry.

	while (true) {
		// If we're not pointing to a digit currently, we lose
		if (!is_digit(*f)) {
			return -1;
		}

		(*f)++;

		if (is_digit(*f)) {
			// We incremented and don't need to carry.  we win.
			return 0;
		}

		*f = '0';

		f--;
	}

}

static void open_log(FIL *fil) {
	char filename[] = LOGNAME_FMT;
	FRESULT res;

	res = f_open(fil, filename, FA_WRITE | FA_CREATE_NEW);

	while (res == FR_EXIST) {
		if (advance_filename(filename)) {
			// ..-. .. .-.. . ...
			led_panic("FILES");
		}

		// This is likely n^2 or worse with number of config files
		res = f_open(fil, filename, FA_WRITE | FA_CREATE_NEW);
	}

	if (res != FR_OK) {
		// --- .-... --- --.
		led_panic("OLOG");
	}

	if (cfg_prealloc > 0) {
		// Attempt to preallocate contig space for the logfile
		// Best effort only-- figure it's better to keep going if
		// we can't alloc it at all.

		f_expand(fil, cfg_prealloc, cfg_prealloc_grow ? 1 : 0);
	}

}

static void fill_lcg(uint32_t *state, uint32_t *buf, int num_words) {
	register uint32_t s = *state;

	for (register int i=0; i<num_words; i++) {
		// Constants for mixed congruential generator from
		// Numerical Recipes.
		s *= 1664525;
		s += 1013904223;

		buf[i] = s;
	}

	*state = s;
}

static int compare_lcg(uint32_t *state, uint32_t *buf, int num_words) {
	register uint32_t s = *state;

	for (register int i=0; i<num_words; i++) {
		// Constants for mixed congruential generator from
		// Numerical Recipes.
		s *= 1664525;
		s += 1013904223;

		if (buf[i] != s) {
			return -1;
		}
	}

	*state = s;

	return 0;
}

static void do_bist(void) {
	/* 120K.  To test writing 6 megabytes, write 50 chunks of this */
	uint32_t buf[120*1024 / sizeof(uint32_t)];

	uint32_t state = 0;

	FRESULT res;
	UINT cnt;
	FIL fil;

	f_unlink("bist.txt");

	/* Create a bist text file */
	res = f_open(&fil, "bist.txt", FA_WRITE | FA_CREATE_NEW);
	if (res != FR_OK) {
		led_panic("BISTOPEN");
	}


	for (int i=0; i<50; i++) {
		fill_lcg(&state, buf, NELEMENTS(buf));

		res = f_write(&fil, buf, sizeof(buf), &cnt);

		if (res != FR_OK) {
			led_panic("BISTWERR");
		}

		if (cnt != sizeof(buf)) {
			led_panic("BISTWSIZE");
		}
	}

	f_close(&fil);

	res = f_open(&fil, "bist.txt", FA_READ | FA_OPEN_EXISTING);

	if (res != FR_OK) {
		led_panic("BISTOPEN2");
	}

	state = 0;
	for (int i=0; i<50; i++) {
		res = f_read(&fil, buf, sizeof(buf), &cnt);

		if (res != FR_OK) {
			led_panic("BISTRERR");
		}

		if (cnt != sizeof(buf)) {
			led_panic("BISTRSIZE");
		}

		if (compare_lcg(&state, buf, NELEMENTS(buf))) {
			led_panic("DERR");
		}
	}

	res = f_unlink("bist.txt");

	if (res != FR_OK) {
		led_panic("ERAS");
	}

	led_panic("SI");	// ... ..
}

static void do_usart_logging(void) {
	char buf[125*1024];

	usart_init(cfg_baudrate, buf, sizeof(buf));

	FIL log_file;

	open_log(&log_file);

	while (1) {
		const char *pos;
		unsigned int amt;

		// 50 ticks == 200ms, prefer 512 byte sector alignment,
		// and >= 2560 byte chunks are best
		// Never get more than about 2/5 of the buffer (40 * 1024)--
		// because we want to finish the IO and free it up
		pos = usart_receive_chunk(50, 512, 5*512,
				40*1024, &amt);

		// Could consider if pos is short, waiting a little longer
		// (400-600ms?) next time...

		led_set(true);	// Illuminate LED during IO

		FRESULT res;

		if (!amt) {
			// If nothing has happened in 200ms, flush our
			// buffers.
			res = f_sync(&log_file);

			if (res != FR_OK) {
				// . .-. .-.
				led_panic("SERR");
			}
		} else {
			UINT written;

			res = f_write(&log_file, pos, amt, &written);

			if (res != FR_OK) {
				// . .-. .-.
				led_panic("WERR");
			}

			if (written != amt) {
				// ..-. ..- .-.. .-..
				led_panic("FULL");
			}
		}

		led_set(false);
	}
}

int main() {
	RCC_DeInit();

	// Wait for internal oscillator settle.
	while (RCC_GetFlagStatus(RCC_FLAG_HSIRDY) == RESET);

	// Turn on the external oscillator
	RCC_HSEConfig(RCC_HSE_ON);

	if (RCC_WaitForHSEStartUp() == ERROR) {
		// Settle for HSI, and flag error.

		// Program the PLL.
		RCC_PLLConfig(RCC_PLLSource_HSI,
				8,	/* PLLM = /8 = 2MHz */
				96,	/* PLLN = *96 = 192MHz */
				2,	/* PLLP = /2 = 96MHz, slight underclock */
				5	/* PLLQ = /5 = 38.4MHz, underclock SDIO
					 * (Maximum is 48MHz)  Will get a 19.2MHz
					 * SD card clock from dividing by 2, or
					 * 9.6MBps at 4 bits wide.
					 */
			);

		osc_err = true;
	} else {
		// Program the PLL.
		RCC_PLLConfig(RCC_PLLSource_HSE,
				4,	/* PLLM = /4 = 2MHz */
				96,	/* PLLN = *96 = 192MHz */
				2,	/* PLLP = /2 = 96MHz, slight underclock */
				5	/* PLLQ = /5 = 38.4MHz, underclock SDIO
					 * (Maximum is 48MHz)  Will get a 19.2MHz
					 * SD card clock from dividing by 2, or
					 * 9.6MBps at 4 bits wide.
					 */
			);
	}

	// Get the PLL starting.
	RCC_PLLCmd(ENABLE);

	// Program this first, just in case we coasted in here with other periphs
	// already enabled.  The loader does all of this stuff, but who knows,
	// maybe in the future our startup code will do less of this.

	RCC_HCLKConfig(RCC_SYSCLK_Div1);	/* AHB = 96MHz */
	RCC_PCLK1Config(RCC_HCLK_Div2);		/* APB1 = 48MHz (lowspeed domain) */
	RCC_PCLK2Config(RCC_HCLK_Div1);		/* APB2 = 96MHz (fast domain) */
	RCC_TIMCLKPresConfig(RCC_TIMPrescDesactivated);
			/* "Desactivate"... the timer prescaler */

	RCC_SYSCLKConfig(RCC_SYSCLKSource_PLLCLK);

	/* SDIO peripheral clocked at 38.4MHz. * 3/8 = minimum APB2 = 14.4MHz,
	 * and we have 96MHz.. so we're good ;) */

	RCC_AHB1PeriphClockCmd(RCC_AHB1Periph_GPIOA |
			RCC_AHB1Periph_GPIOB |
			RCC_AHB1Periph_GPIOC |
			RCC_AHB1Periph_GPIOD |
			RCC_AHB1Periph_GPIOE |
			RCC_AHB1Periph_DMA2,
			ENABLE);

	RCC_APB1PeriphClockCmd(RCC_APB1Periph_TIM2 |
			RCC_APB1Periph_TIM3 |
			RCC_APB1Periph_TIM4 |
			RCC_APB1Periph_TIM5,
			ENABLE);

	RCC_APB2PeriphClockCmd(RCC_APB2Periph_TIM1 |
			RCC_APB2Periph_USART1 |
			RCC_APB2Periph_SPI1 |
			RCC_APB2Periph_SYSCFG |
			RCC_APB2Periph_SDIO,
			ENABLE);

	/* Seize PA14/PA13 from SWD. */
	GPIO_InitTypeDef swd_def = {
		.GPIO_Pin = GPIO_Pin_14 | GPIO_Pin_13,
		.GPIO_Mode = GPIO_Mode_IN,	// Input, not AF
		.GPIO_Speed = GPIO_Low_Speed,
		.GPIO_OType = GPIO_OType_PP,
		.GPIO_PuPd = GPIO_PuPd_NOPULL
	};

	GPIO_Init(GPIOA, &swd_def);

	// Program 3 wait states as necessary at >2.7V for 96MHz
	FLASH_SetLatency(FLASH_Latency_3);

	// Wait for the PLL to be ready.
	while (RCC_GetFlagStatus(RCC_FLAG_PLLRDY) == RESET);

	SysTick_Config(96000000/250);	/* 250Hz systick */

	/* Real hardware has LED on PB9. (sink on) */
	led_init_pin(GPIOB, GPIO_Pin_9, true);

	/* Discovery hardware has blue LED on PD15. */
	/* led_init_pin(GPIOD, GPIO_Pin_15, false); */

	if (osc_err) {
		// blink an error; though this is nonfatal.
		led_send_morse("XOSC ");
	}

        if (sd_init(false)) {
                // -.-. .- .-. -..
                led_panic("CARD");
        }

        if (f_mount(&fatfs, "0:", 1) != FR_OK) {
                // -.. .- - .-
                led_panic("DATA ");
        }

	process_config();

	if (cfg_bist) {
		do_bist();
	}

	do_usart_logging();

	return 0;
}

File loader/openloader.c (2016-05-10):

// OpenLager bootloader
//
// Copyright (c) 2016, dRonin
// All rights reserved.
//
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
// THIS SOFTWARE IS PROVIDED BY THE COPYRIGHT HOLDERS AND CONTRIBUTORS "AS IS" AND
// ANY EXPRESS OR IMPLIED WARRANTIES, INCLUDING, BUT NOT LIMITED TO, THE IMPLIED
// WARRANTIES OF MERCHANTABILITY AND FITNESS FOR A PARTICULAR PURPOSE ARE
// DISCLAIMED. IN NO EVENT SHALL THE COPYRIGHT OWNER OR CONTRIBUTORS BE LIABLE FOR
// ANY DIRECT, INDIRECT, INCIDENTAL, SPECIAL, EXEMPLARY, OR CONSEQUENTIAL DAMAGES
// (INCLUDING, BUT NOT LIMITED TO, PROCUREMENT OF SUBSTITUTE GOODS OR SERVICES;
// LOSS OF USE, DATA, OR PROFITS; OR BUSINESS INTERRUPTION) HOWEVER CAUSED AND
// ON ANY THEORY OF LIABILITY, WHETHER IN CONTRACT, STRICT LIABILITY, OR TORT
// (INCLUDING NEGLIGENCE OR OTHERWISE) ARISING IN ANY WAY OUT OF THE USE OF THIS
// SOFTWARE, EVEN IF ADVISED OF THE POSSIBILITY OF SUCH DAMAGE.
//

#include <stdbool.h>

#include <stm32f4xx_flash.h>
#include <stm32f4xx_rcc.h>

#include <systick_handler.h>

#include <sdio.h>
#include <ff.h>

#include <led.h>

extern uint32_t _efill;

const void *_interrupt_vectors[FPU_IRQn] __attribute((section(".interrupt_vectors"))) = {
};

#define MAINPROGRAM_OFFSET 0x08010000 // from src/memory.ld
void invoke_next_program()
{
	// XXX should deinit interrupt-y things here... or at least mask
	// interrupts.
	RCC_APB2PeriphResetCmd(0xffffffff, ENABLE);
	RCC_APB1PeriphResetCmd(0xffffffff, ENABLE);
	RCC_APB2PeriphResetCmd(0xffffffff, DISABLE);
	RCC_APB1PeriphResetCmd(0xffffffff, DISABLE);

	void *memory = (void *) MAINPROGRAM_OFFSET;

	register uintptr_t stack_pointer asm ("r0") = *((const uintptr_t *)(memory));
	register uintptr_t program_entry asm ("r1") = *((const uintptr_t *)(memory + sizeof(void *)));

	asm volatile (
		"mov	sp, r0\n\t"
		"msr	MSP, r0\n\t"
		"bx	r1\n\t"
		: "+r" (stack_pointer), "+r" (program_entry)
		: :);   // No clobbers etc, because this never comes back.

	__builtin_unreachable();
}

void chk_flashop(FLASH_Status f)
{
	if (f != FLASH_COMPLETE) {
		while (1) {
			// ..-. . .-. .-.
			led_panic("FERR");
		}
	}
}

/* If anything goes wrong here, we'll still go to the main program.
 * But it's doubtful, because things going wrong here are likely to
 * affect the main program too.  So we are willing to pay the penalty
 * to flash an error code.
 */
void try_loader_stuff()
{
	/* Real hardware has LED on PB9. (sink on) */
	led_init_pin(GPIOB, GPIO_Pin_9, true);

	/* Discovery hardware has blue LED on PD15. */
	/* led_init_pin(GPIOD, GPIO_Pin_15, false); */

	if (sd_init(false)) {
		// -.-. .- .-. -..
		led_send_morse("CARD ");
		return;
	}

	FATFS fatfs;

	if (f_mount(&fatfs, "0:", 1) != FR_OK) {
		// -.. .- - .-
		led_send_morse("DATA ");
		return;
	}

	FIL fil;

	if (f_open(&fil, "0:lager.bin", FA_READ) != FR_OK) {
		// Missing image is not an error -> we don't blink
		return;
	}

	uint32_t *prog_flash = &_efill;
	UINT amount;

	bool diff = false;

	// XXX elim magic number.
	uint32_t buf[16384];    // Nice to have a lot of ram;
	                        // can safely use 64k on this stack
	                        // frame on the loader.

	/* XXX Ideally we would set up to flash larger than 64k
	 * programs, since there's 192k of flash... */
	if (FR_OK != f_read(&fil, buf, sizeof(buf), &amount)) {
		// .. ---
		led_send_morse("IO ");
		return;
	}

	if ((amount < 500) || (amount % sizeof(*buf))) {
		// Very short or not an integral number of words.
		led_send_morse("TRUNC ");
		return;
	}

	amount /= sizeof(*buf);         // convert into word count

	for (int i = 0; i < amount; i++) {
		if (buf[i] != prog_flash[i]) {
			diff = true;

			// ..- .--.   ..- .--.
			led_send_morse("UP UP ");

			break;
		}
	}

	if (!diff) {
		// no update necessary.. go to main firmware.
		return;
	}

	FLASH_Unlock();

	// checks success, infloop blinking if not
	chk_flashop(FLASH_EraseSector(FLASH_Sector_4, VoltageRange_3));

	led_send_morse("PRG ");

	for (int i = 0; i < amount; i++) {
		chk_flashop(FLASH_ProgramWord((uint32_t) (prog_flash + i),
				buf[i]));
	}

	led_send_morse(".. ");

	FLASH_Lock();
}

int main()
{
	/* Keep it really simple in the loader-- just run from 16MHz RC osc,
	 * no wait states, etc. */
	RCC_DeInit();

	/* Wait for the internal oscillator, not that we expect to need
	 * it.
	 */
	while (RCC_GetFlagStatus(RCC_FLAG_HSIRDY) == RESET);

	RCC_HCLKConfig(RCC_SYSCLK_Div1);        /* AHB = 16MHz */
	RCC_PCLK1Config(RCC_HCLK_Div1);         /* APB1 = 16MHz */
	RCC_PCLK2Config(RCC_HCLK_Div1);         /* APB2 = 16MHz */
	RCC_TIMCLKPresConfig(RCC_TIMPrescDesactivated);
	/* "Desactivate"... the timer prescaler */

	/* The PLL is necessary to talk to the SDIO peripheral */
	RCC_PLLConfig(RCC_PLLSource_HSI,
			8,      /* PLLM = /8 = 2MHz */
			96,     /* PLLN = *96 = 192MHz */
			2,      /* PLLP = /2 = 96MHz, but not used */
			5       /* PLLQ = /5 = 38.4MHz, underclock SDIO
	                         * (Maximum is 48MHz)  Will get a 19.2MHz
	                         * SD card clock from dividing by 2, or
	                         * 9.6MBps at 4 bits wide.
	                         */
			);

	/* SDIO peripheral clocked at 38.4MHz.  minimum APB2 = 14.4MHz,
	 * and we have 16MHz.. so we're good */

	/* Enable and wait for the PLL */
	RCC_PLLCmd(ENABLE);

	while (RCC_GetFlagStatus(RCC_FLAG_PLLRDY) == RESET);

	RCC_AHB1PeriphClockCmd(RCC_AHB1Periph_GPIOA |
			RCC_AHB1Periph_GPIOB |
			RCC_AHB1Periph_GPIOC |
			RCC_AHB1Periph_GPIOD |
			RCC_AHB1Periph_GPIOE,
			ENABLE);

	RCC_APB1PeriphClockCmd(RCC_APB1Periph_TIM2 |
			RCC_APB1Periph_TIM3 |
			RCC_APB1Periph_TIM4 |
			RCC_APB1Periph_TIM5,
			ENABLE);

	RCC_APB2PeriphClockCmd(RCC_APB2Periph_TIM1 |
			RCC_APB2Periph_USART1 |
			RCC_APB2Periph_SPI1 |
			RCC_APB2Periph_SYSCFG |
			RCC_APB2Periph_SDIO,
			ENABLE);

	/* Seize PA14/PA13 from SWD. */
	GPIO_InitTypeDef swd_def = {
		.GPIO_Pin = GPIO_Pin_14 | GPIO_Pin_13,
		.GPIO_Mode = GPIO_Mode_IN,
		.GPIO_Speed = GPIO_Low_Speed,
		.GPIO_OType = GPIO_OType_PP,
		.GPIO_PuPd = GPIO_PuPd_NOPULL
	};

	GPIO_Init(GPIOA, &swd_def);

	SysTick_Config(16000000/250);   /* 250Hz systick */

	try_loader_stuff();

	invoke_next_program();

	return 0;
}

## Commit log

2016-04-17 Import STM32F4xx_StdPeriph_Driver. (#4)
    License was saved from
    http://www.st.com/software_license_agreement_liberty_v2
2016-04-18 Startup code, linker scripts, makefile.. and misc housekeeping. (#9)
    * Move license to be consistent with droid's tree
    * Get initial startup code and main in
    Produce basic ELF contents, too. Superficially appears correct for this
    trivial case.
    [openlager.c]
2016-04-19 various fixes, stub out hardware init (#11)
    [openloader.c]
2016-04-19 further work on getting target to start (#12)
    * There's a systick handler and provisions for interrupt vectors.
    * The linker script is altered to treat data right.
    * We initialize the PLL and wait for clocks to be operational.
2016-04-19 Initial hw files (#8)
    * Initial draft of HW for review
    * Adding the design and output files
    * Minor tweaks as per @mlyle review
    [openLager-B.Cu.gbl, openLager-B.Mask.gbs, openLager-B.SilkS.gbo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]
2016-04-19 Get running in emulator (#14)
    * Teach makefile to make bin files with objcopy
    * Disable floating point init for now
    This allows GNU-ARM-Eclipse-QEMU to emulate the board without failing
    out.
    Command line I'm currently using is:
    `/Applications/GNU\ ARM\ Eclipse/QEMU/2.4.50-201510290935-dev/bin/qemu-system-gnuarmeclipse -board NUCLEO-F411RE -image build/openloader.bin`
2016-04-19 openloader: get to the point where it can blink LED (#15)
2016-04-19 Many changes towards functional bootloader support. (#16)
    * Pad firmware images to full size with 0xff
    * Add new ef_lager.bin which is the "entire firmware" like dR.
    * Implement new invoke_next_program in loader which chains to the
    next program
    * Synchronized code between openloader and openlager.
    * Adjust LED blink behavior so I can tell the difference between
    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
2016-04-20 Get code to the point where it fails initing SD on discovery board hardware (#19)
    * Note using openlager logo requires permission
    * sdio: get the code to perhaps be ready to init
    * morsel: teach to delay & blit GPIOs
    * teach loader to send some morse for bringup
    * sdio: correct pin af initialization
    * adjust to do LED on discovery board
    [openlager.c, openloader.c, sdio.c]
2016-04-21 sdio/loader: now to the point it can read a file (#21)
    It flashes out Alice's Adventures in Wonderland in morse code with
    this current version from the bootloader.
    [flash.cfg]
2016-04-21 sdio/loader: now a complete functional bootloader (#22)
    * alter startup code to properly set vector loc
    * The loader is now a complete loader
    * Make filenames more fun
    [flash.cfg]
2016-04-21 Main program (not loader) runs with faster clock (#23)
    * make: compile with -Werror, we're clean
    * clocking: clock at cpu=96MHz sd=38.4MHz apb1=48MHz
    Still uses the internal oscillator as the PLL source while on
    development hardware.
    [openlager.c]
2016-04-23 stub out more code, factor nicer (#24)
    * Add minimal USART configuration stub.
    * Add jsmn library to source code
    * Build using ccache if possible, to compile fast
    * improve shared code structure, adjust namespaces
    * In the main code, use the external oscillator.
    * Stub out code to disable the SWD pins
    * Fixups for USART support
    * Blink an error when external osc does not start
    [led.c, openlager.c, openloader.c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]
2016-04-23 assorted work, getting write path to SD functional (#25)
    * adjust fatfs config for performance
    * led: store speed to send morse in led module
    * add sd write path
    * add config file processing stub
    * correct clock frequency when using ext osc
    * config: improve the default config write process
    [lager.cfg]
2016-04-24 stack and memory analysis, plus small additional work towards logging (#26)
    * sdio: use flow control; prevent overruns/underruns
    * Add stack analysis stuff.
    It works! My command lines look like:
    ```
    make clean
    STACK_USAGE=1 make -j4
    ./misc/avstack.pl `find build | grep .o$ | grep -v ^build/loader` | less
    ```
    or, to look at the loader only:
    ```
    ./misc/avstack.pl `find build | grep .o$ | grep -v ^build/src` | less
    ```
    * Teach makefile to gather stack usage information
    (Triggered by building as `STACK_USAGE=1 make`)
    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
    [openlager.c, sdio.c, usart.c]
2016-04-25 Make it actually work as a logger (#27)
    * Add rudimentary USART RX code.
    * Add basic log-file selection logic.
    * usart: Add RX API call
    * add minimal logging code
    * Minimally implement fatfs diskio "sync"
    Since we don't buffer / cache this doesn't need to do anything.
    * sdio: disable hardware flow control, adjust timeouts
    * Minor improvements to openlager structure
    * Properly enable USART interrupts
    * Fix an off by one error in USART buffer management
    [openlager.c, sdio.c, usart.c]
2016-04-25 Add retries to SD layer (#31)
    * Turn off SD morse debugging
    * Teach to abort transfers and retry on failure
    [sdio.c]
2016-04-25 Adding BOM and tweaked solder paste layer (#35)
    * Adding BOM and tweaked solder paste layer
    * Clean up Link on J1 and TP*
    [openLager-B.Cu.gbl, openLager-B.Mask.gbs, openLager-B.Paste.gbp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]
2016-04-25 Disable SWD pins, adjust programming config (#36)
    * Add ST errata note to sdio.c.
    * Disable SWD once firmware running / out of reset
    [flash.cfg]
2016-04-26 add configuration support (#38)
    Performance was validated at 1,152,000 bps with no drops on a 4 megabyte log. at 1,500,000 bps we still lose some on prototype hardware (1x SDIO) with no DMA enabled and no multiple-block writes.
    [lager.cfg]
2016-04-26 uncrustify all the code (#40)
    Thankfully this has resulted in minimal change to the code, mostly in
    bracket conventions after function definitions and spaces (instead of
    tabs) for alignment of comments.
2016-04-27 DFM changes and added SS RefDes (#41)
    [openLager-B.Cu.gbl, openLager-B.Mask.gbs, openLager-B.Paste.gbp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]
2016-04-28 Put dRonin logo on board (#42)
    [openLager-B.Cu.gbl, openLager-B.Mask.gbs, openLager-B.Paste.gbp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]
2016-05-02 Introduce support for DMA on write. (#44)
    Fixes #30.
    [openlager.c, sdio.c]
2016-05-02 hw: bom: Adjust format to one-line-per-PN (#43)
    So that multiple refdeses can be on one line. Easier to place from,
    plays nicer with OctoPart.
    [openLager_BOM.csv]
2016-05-03 add preallocation infrastructure and increase buffer sizes (#46)
    * sdio: correct constant name
    No functional change; just the preferred constant #define used
    * add preallocation infrastructure
    can either update file / claim space immediately to lower write
    amplification, or can just find a contiguous section of desired size.
    * Write slightly longer chunks at a time.
    * increase buffer size by 25%
    Huzzah having stack analysis and no RTOS for this simple stuff, because
    it lets us squeeze every bit out of the hardware.
    Analysis says:
    Memory used by data+BSS: 644
    Peak execution estimate (main + worst-case IV):
    main = 128992, worst IV = 24, total = 129016
    129016 + 64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
    [lager.cfg]
2016-05-10 move LED and LED sense to non-eval hardware config (#47)
    * move LED and LED sense to non-eval hardware config
    * loader: also move to production hw config
2016-05-10 loader: woops: fix it so LED actually works (#49)
    [openloader.c]
2016-05-19 Hardware rev b (#50)
    * Updated to RevB, changed LED and SS
    * Adding new BOM
    * Changing SCH rev
    * Change /NRST from pin to TP
    [openLager-B.Cu.gbl, openLager-B.Mask.gbs, openLager-B.Paste.gbp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]
2016-06-16 Add (very simple) fab drawing to openlager. (#51)
    [openLager-B.Cu.gbl, openLager-B.Mask.gbs, openLager-B.Paste.gbp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]
2016-06-29 Add built-in self test mode to openlager. (#52)
    To be used in manufacturing/fulfillment. It's really simple right now:
    write 6 megabytes of data to a filesystem, read it back, blink LEDs.

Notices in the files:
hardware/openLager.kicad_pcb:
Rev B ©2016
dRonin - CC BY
